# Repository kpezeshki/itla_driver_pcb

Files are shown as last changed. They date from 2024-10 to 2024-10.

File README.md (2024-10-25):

Board is generally functional but improvements are possible:

1. The hole size for the meanwell power supply modules is too small, so the modules need to be hacked to fit.

2. The UART module is too far from the board edge. Need to check footprint and shift closer.

Use a 40 mm half-height fan to cool the ITLA.

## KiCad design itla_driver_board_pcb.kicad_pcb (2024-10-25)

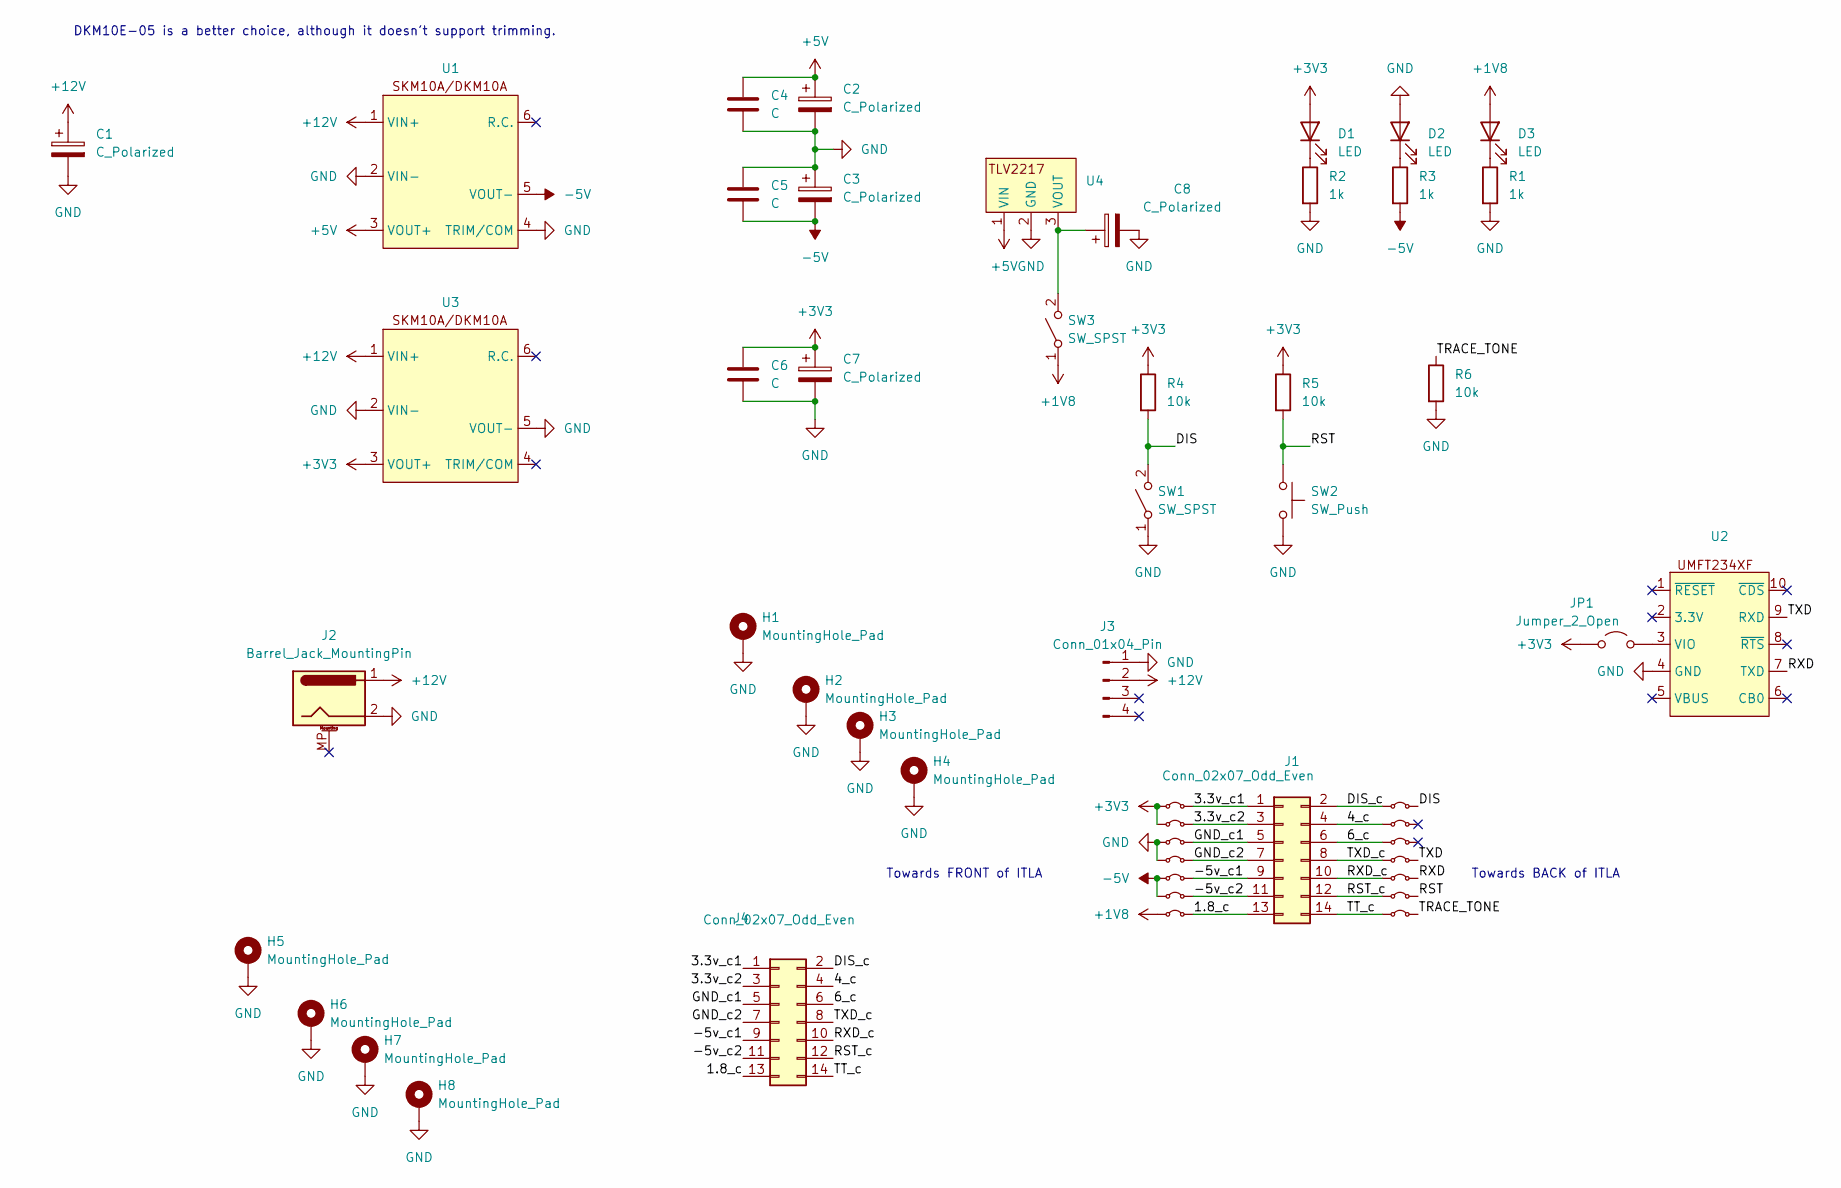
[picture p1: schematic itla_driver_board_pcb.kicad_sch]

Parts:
C1, C2, C3, C7, C8: C_Polarized; CP_Radial_D12.5mm_P5.00mm
C4, C5, C6: C; C_Disc_D10.0mm_W2.5mm_P5.00mm
D1, D2, D3: LED; LED_D5.0mm
H1, H2, H3, H4, H5, H6, H7, H8: MountingHole_Pad; MountingHole_3.2mm_M3_Pad
J1: Conn_02x07_Odd_Even; PinHeader_2x07_P1.00mm_Vertical_SMD
J2: Barrel_Jack_MountingPin; BarrelJack_CUI_PJ-063AH_Horizontal
J3: Conn_01x04_Pin; PinHeader_1x04_P2.54mm_Vertical
J4: Conn_02x07_Odd_Even; ITLA
JP1: Jumper_2_Open; SolderJumper-2_P1.3mm_Open_Pad1.0x1.5mm
JP2, JP3, JP4, JP5, JP6, JP7, JP8, JP9, JP10, JP11, JP12, JP13, JP14, JP15: Jumper_2_Small_Bridged; SolderJumper-2_P1.3mm_Bridged_Pad1.0x1.5mm
R1, R2, R3: 1k; R_Axial_DIN0207_L6.3mm_D2.5mm_P7.62mm_Horizontal
R4, R5, R6: 10k; R_Axial_DIN0207_L6.3mm_D2.5mm_P7.62mm_Horizontal
SW1, SW3: SW_SPST; SW_E-Switch_EG1271_SPDT
SW2: SW_Push; SW_SPST_Omron_B3F-40xx
U1, U3: SKM10
U2: UMFT234XF
U4: TO-220-3_Vertical

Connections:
+1V8: D3.2 (A), JP15.1 (A), SW3.1 (A)
+3V3: C6.1, C7.1, D1.2 (A), JP1.1 (A), JP9.1 (A), JP10.1 (A), R4.1, R5.1, U3.3 (VOUT+)
+5V: C2.1, C4.1, U1.3 (VOUT+), U4.1 (VIN)
+12V: C1.1, J2.1, J3.2, U1.1 (VIN+), U3.1 (VIN+)
-5V: C3.2, C5.2, JP13.1 (A), JP14.1 (A), R3.2, U1.5 (VOUT-)
/1.8_c: J1.13, J4.13, JP15.2 (B)
/3.3v_c1: J1.1, J4.1, JP9.2 (B)
/3.3v_c2: J1.3, J4.3, JP10.2 (B)
/4_c: J1.4, J4.4, JP7.1 (A)
/6_c: J1.6, J4.6, JP8.1 (A)
/-5v_c1: J1.9, J4.9, JP13.2 (B)
/-5v_c2: J1.11, J4.11, JP14.2 (B)
/DIS: JP2.2 (B), R4.2, SW1.2 (B)
/DIS_c: J1.2, J4.2, JP2.1 (A)
/GND_c1: J1.5, J4.5, JP11.2 (B)
/GND_c2: J1.7, J4.7, JP12.2 (B)
/RST: JP5.2 (B), R5.2, SW2.1
/RST_c: J1.12, J4.12, JP5.1 (A)
/RXD: JP4.2 (B), U2.7 (TXD)
/RXD_c: J1.10, J4.10, JP4.1 (A)
/TRACE_TONE: JP6.2 (B), R6.1
/TT_c: J1.14, J4.14, JP6.1 (A)
/TXD: JP3.2 (B), U2.9 (RXD)
/TXD_c: J1.8, J4.8, JP3.1 (A)
GND: C1.2, C2.2, C3.1, C4.2, C5.1, C6.2, C7.2, C8.2, D2.2 (A), H1.1, H2.1, H3.1, H4.1, H5.1, H6.1, H7.1, H8.1, J2.2, J3.1, JP11.1 (A), JP12.1 (A), R1.2, R2.2, R6.2, SW1.1 (A), SW2.2, U1.2 (VIN-), U1.4 (TRIM/COM), U2.4 (GND), U3.2 (VIN-), U3.5 (VOUT-), U4.2 (GND)
unnamed: D1.1 (K), R2.1
unnamed: D2.1 (K), R3.1
unnamed: D3.1 (K), R1.1
unnamed: JP1.2 (B), U2.3 (VIO)
unnamed: C8.1, SW3.2 (B), U4.3 (VOUT)

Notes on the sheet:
Towards FRONT of ITLA
DKM10E-05 is a better choice, although it doesn't support trimming.
Towards BACK of ITLA

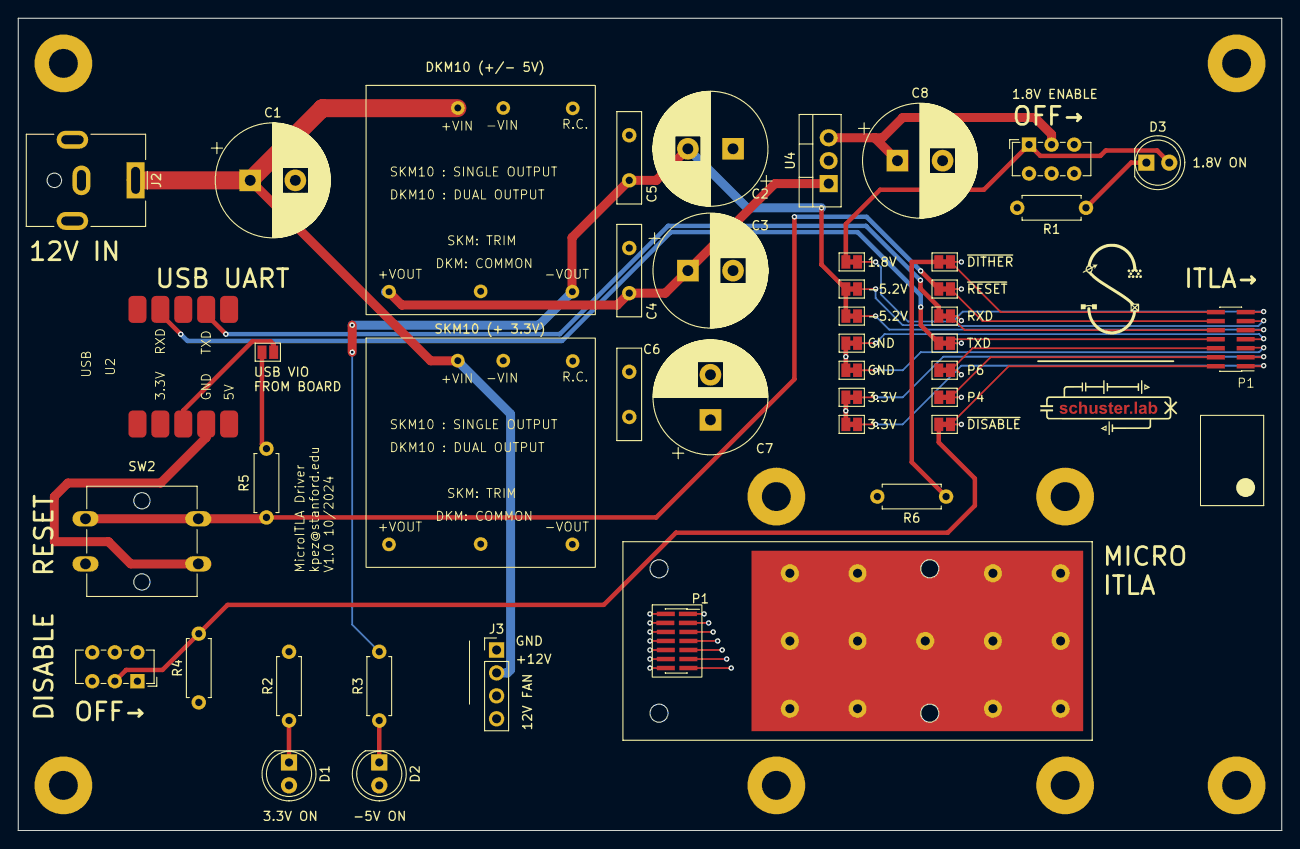
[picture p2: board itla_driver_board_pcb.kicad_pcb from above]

Board: 4 copper layers, 140.0 x 90.0 mm, 51 parts (0 on the bottom side), 30 nets.
